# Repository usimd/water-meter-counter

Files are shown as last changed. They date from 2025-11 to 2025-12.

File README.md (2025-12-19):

# Inductive water meter counter with S0 interface for GSB-8 meters

This is a custom water meter counter project to get an interface to analog water meter readings
for subsequent usage in Homeassistant. The project is outputting its readings via a generic S0
interface, though, to enable other use cases as well.

It features a custom 3D-printable model to snap on to the GSB-8 meter that houses the PCB. The
software doing the actual work is located in the [`firmware`](./firmware) folder. Since it is
based on a Microchip PIC controller, it requires the respective infrastructure to build.

Bundled assets are available as GitHub releases, including compiled firmware, 3MF file of the
housing and Gerber files for PCB production.

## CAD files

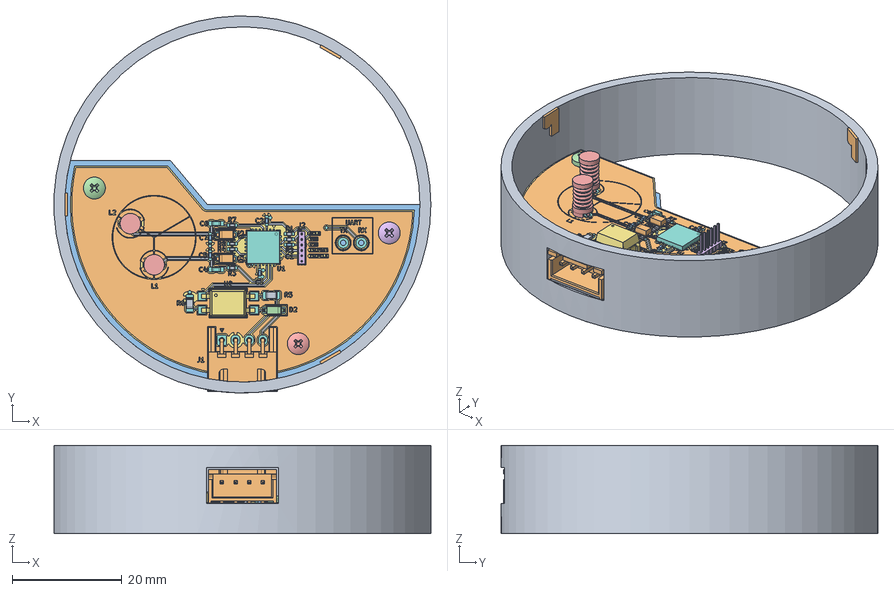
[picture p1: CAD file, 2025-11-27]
Watermeter_Cover.FCStd
68.8 x 68.8 x 16.1 mm
Cover_Base
Pins
PCB_Mount
M2x5-Schraube
M2x5-Schraube003
M2x5-Schraube004
Pcb_d2e1
topPads_d2e1
topTracks_d2e1
topZones_d2e1
botPads_d2e1
botTracks_d2e1
botZones_d2e1
botSilks_9d78
topSilks_90ac
C4_C_0603_1608Metric_6c412fb28b8f x 2
R8_R_0402_1005Metric_e01b41909d19 x 6
D1_D_SOD_123F_9a9cfb070a70 x 2
C7_C_0402_1005Metric_09611c456d0c x 5
D2_D_SOD-123_464a0c5e4694
L1_Fusion_5f2570e535e7 x 2
J2_PinHeader_1x06_P100mm_Vertical_8e52eaff288e
U2_SSO_4_67x51mm_P254mm_Clearance8mm_ef5c1f87034f
U1_QFN-28-1EP_6x6mm_Pitch0.65mm_9500fd6ea776
R5_R_0805_2012Metric_8a1f76670d96 x 2
J1_JST_S4B_XH_A_36b230cda832

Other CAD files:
Watermeter_Cover.3mf
water-meter-counter-B_Silkscreen.dxf
water-meter-counter-F_Silkscreen.dxf

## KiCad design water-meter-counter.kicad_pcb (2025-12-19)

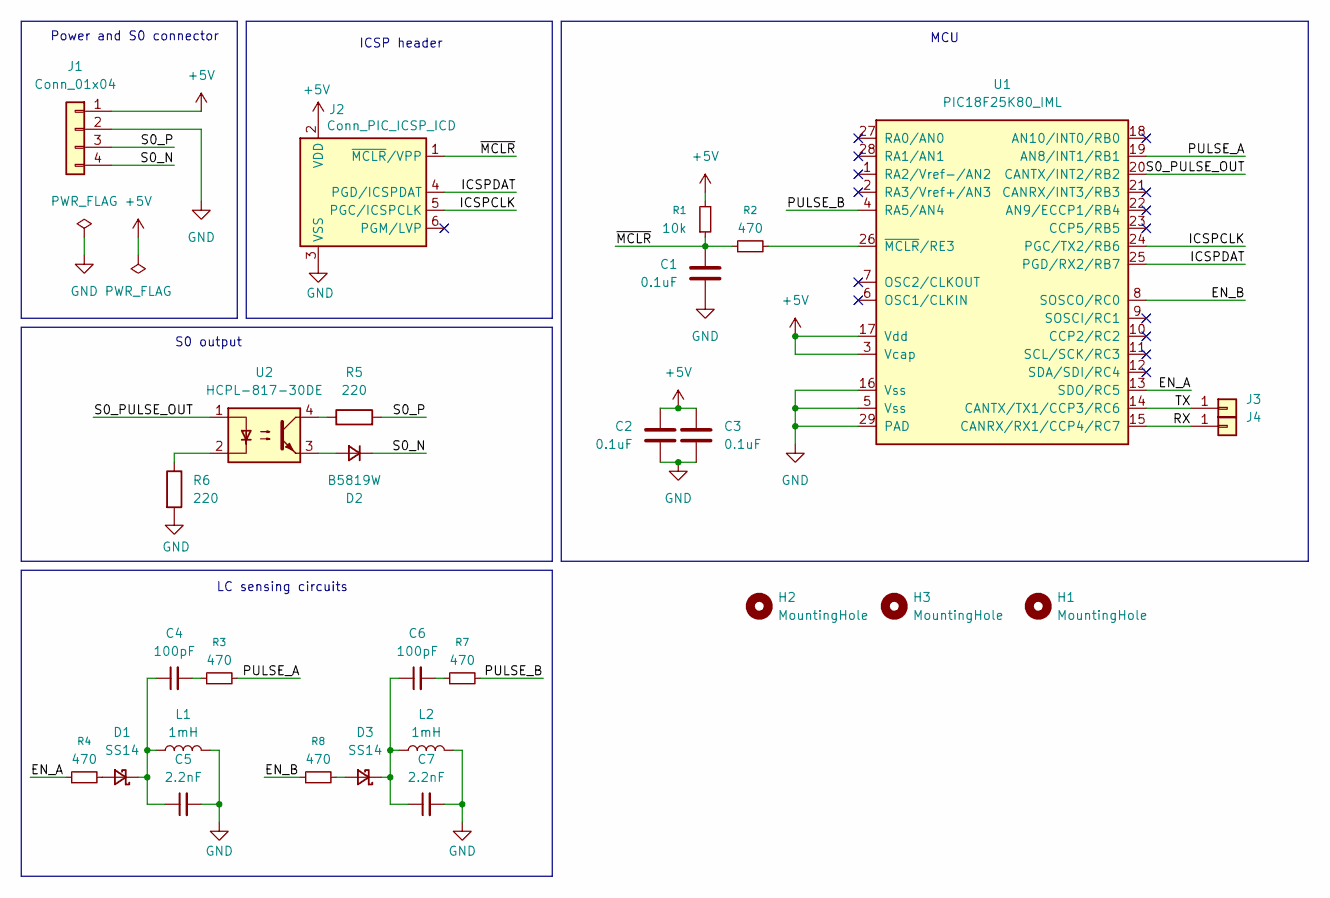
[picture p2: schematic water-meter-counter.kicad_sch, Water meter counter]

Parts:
C1, C2, C3: 0.1uF; C_0402_1005Metric_Pad0.74x0.62mm_HandSolder
C4, C6: 100pF; C_0603_1608Metric_Pad1.08x0.95mm_HandSolder
C5, C7: 2.2nF; C_0402_1005Metric_Pad0.74x0.62mm_HandSolder
D1, D3: SS14; D_SOD-123F
D2: B5819W; D_SOD-123
H1, H2, H3: MountingHole; MountingHole_2.2mm_M2_ISO7380
J1: Conn_01x04; JST_XH_S4B-XH-A_1x04_P2.50mm_Horizontal
J2: Conn_PIC_ICSP_ICD; PinHeader_1x06_P1.00mm_Vertical
J3, J4: Conn_01x01; TestPoint_Keystone_5000-5004_Miniature
L1, L2: 1mH; L_Radial_D4.80mm_P2.50mm_Fastron_05HCP; MPN 05HCP-102K-51
R1: 10k; R_0402_1005Metric_Pad0.72x0.64mm_HandSolder
R2, R3, R4, R7, R8: 470; R_0402_1005Metric_Pad0.72x0.64mm_HandSolder
R5, R6: 220; R_0805_2012Metric_Pad1.20x1.40mm_HandSolder
U1: PIC18F25K80_IML; QFN-28-1EP_6x6mm_P0.65mm_EP4.25x4.25mm
U2: HCPL-817-30DE; SSO-4_6.7x5.1mm_P2.54mm_Clearance8mm

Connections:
+5V: C2.1, C3.1, J1.1, J2.2 (VDD), R1.2, U1.3 (Vcap), U1.17 (Vdd)
/EN_A: R4.1, U1.13 (SDO/RC5)
/EN_B: R8.1, U1.8 (SOSCO/RC0)
/ICSPCLK: J2.5 (PGC/ICSPCLK), U1.24 (PGC/TX2/RB6)
/ICSPDAT: J2.4 (PGD/ICSPDAT), U1.25 (PGD/RX2/RB7)
/PULSE_A: R3.2, U1.19 (AN8/INT1/RB1)
/PULSE_B: R7.2, U1.4 (RA5/AN4)
/RX: J4.1, U1.15 (CANRX/RX1/CCP4/RC7)
/S0_N: D2.1 (K), J1.4
/S0_P: J1.3, R5.2
/S0_PULSE_OUT: U1.20 (CANTX/INT2/RB2), U2.1
/TX: J3.1, U1.14 (CANTX/TX1/CCP3/RC6)
/~MCLR: C1.1, J2.1 (~MCLR/VPP), R1.1, R2.1
GND: C1.2, C2.2, C3.2, C5.2, C7.2, J1.2, J2.3 (VSS), L1.2, L2.2, R6.2, U1.5 (Vss), U1.16 (Vss), U1.29 (PAD)
unnamed: C4.2, R3.1
unnamed: C6.2, R7.1
unnamed: D1.2 (A), R4.2
unnamed: C4.1, C5.1, D1.1 (K), L1.1
unnamed: D2.2 (A), U2.3
unnamed: D3.2 (A), R8.2
unnamed: C6.1, C7.1, D3.1 (K), L2.1
unnamed: R5.1, U2.4
unnamed: R6.1, U2.2
unnamed: R2.2, U1.26 (~MCLR/RE3)

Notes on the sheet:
LC sensing circuits
MCU
ICSP header
Power and S0 connector
S0 output

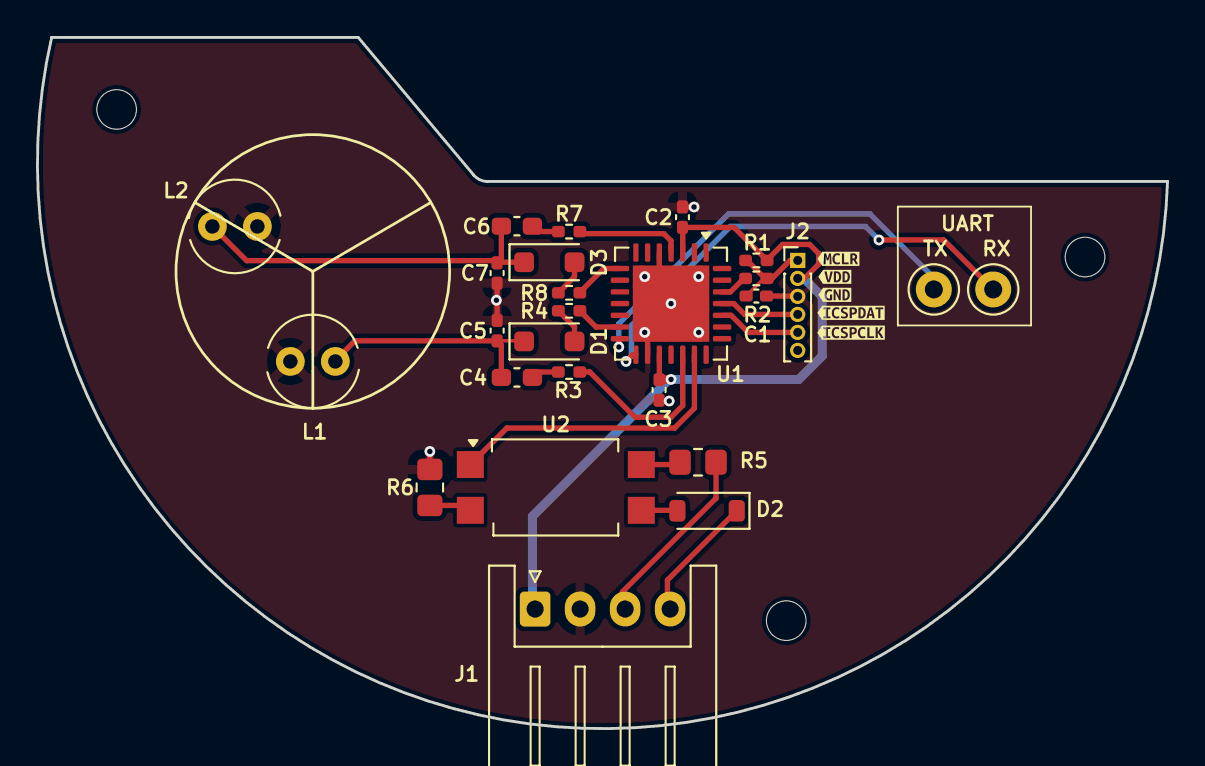
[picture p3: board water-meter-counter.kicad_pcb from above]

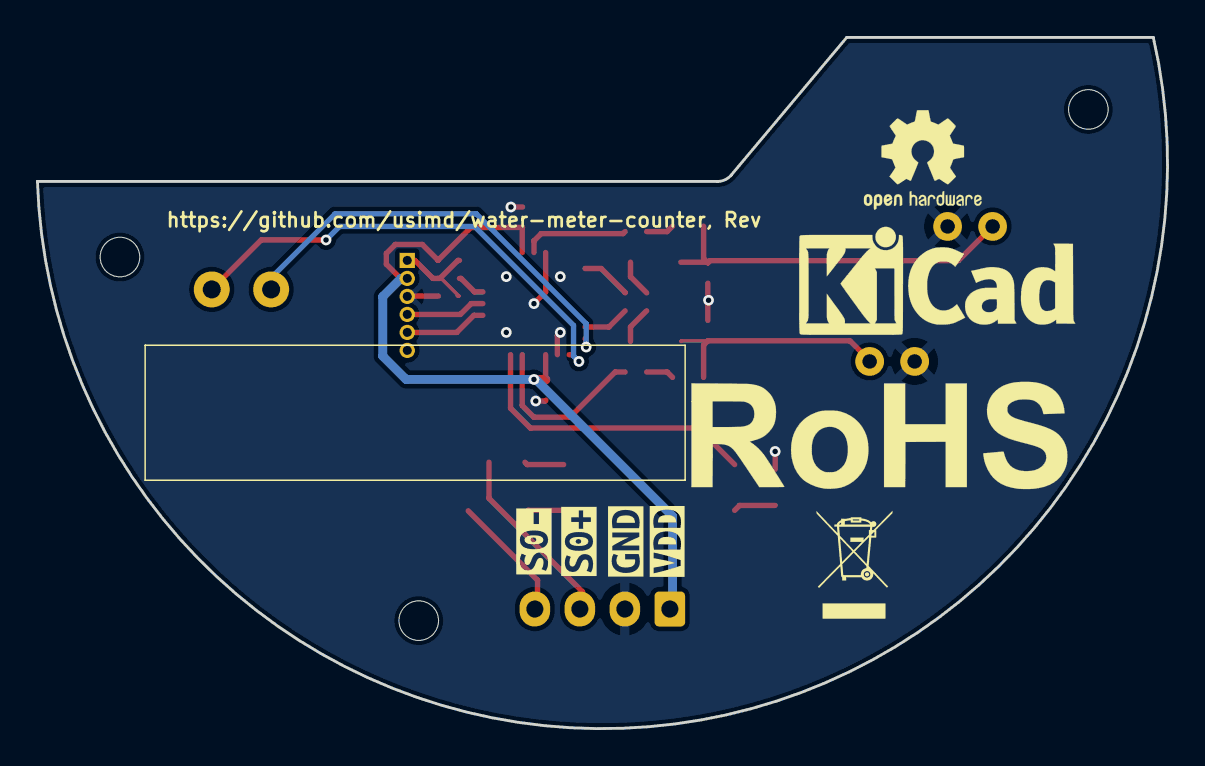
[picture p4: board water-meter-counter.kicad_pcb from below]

Board: 2 copper layers, 62.8 x 38.4 mm, 38 parts (4 on the bottom side), 24 nets.

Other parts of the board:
kibuzzard-6924F1AD: G***; kibuzzard-6924F1AD
kibuzzard-6924F10E: G***; kibuzzard-6924F10E
kibuzzard-6924F13D: G***; kibuzzard-6924F13D
kibuzzard-6924F19F: G***; kibuzzard-6924F19F
kibuzzard-6924F128: G***; kibuzzard-6924F128
kibuzzard-6924F218: G***; kibuzzard-6924F218
kibuzzard-6924F221: G***; kibuzzard-6924F221
kibuzzard-6945164F: G***; kibuzzard-6945164F
kibuzzard-69451647: G***; kibuzzard-69451647

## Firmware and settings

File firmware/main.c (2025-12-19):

 /*
 * MAIN Generated Driver File
 * 
 * @file main.c
 * 
 * @defgroup main MAIN
 * 
 * @brief This is the generated driver implementation file for the MAIN driver.
 *
 * @version MAIN Driver Version 1.0.2
 *
 * @version Package Version: 3.1.2
*/

/*
? [2025] Microc� [2025] Microchip Technology Inc. and its subsidiaries.

    Subject to your compliance with these terms, you may use Microchip 
    software and any derivatives exclusively with Microchip products. 
    You are responsible for complying with 3rd party license terms  
    applicable to your use of 3rd party software (including open source  
    software) that may accompany Microchip software. SOFTWARE IS ?AS IS.? 
    NO WARRANTIES, WHETHER EXPRESS, IMPLIED OR STATUTORY, APPLY TO THIS 
    SOFTWARE, INCLUDING ANY IMPLIED WARRANTIES OF NON-INFRINGEMENT,  
    MERCHANTABILITY, OR FITNESS FOR A PARTICULAR PURPOSE. IN NO EVENT 
    WILL MICROCHIP BE LIABLE FOR ANY INDIRECT, SPECIAL, PUNITIVE, 
    INCIDENTAL OR CONSEQUENTIAL LOSS, DAMAGE, COST OR EXPENSE OF ANY 
    KIND WHATSOEVER RELATED TO THE SOFTWARE, HOWEVER CAUSED, EVEN IF 
    MICROCHIP HAS BEEN ADVISED OF THE POSSIBILITY OR THE DAMAGES ARE 
    FORESEEABLE. TO THE FULLEST EXTENT ALLOWED BY LAW, MICROCHIP?S 
    TOTAL LIABILITY ON ALL CLAIMS RELATED TO THE SOFTWARE WILL NOT 
    EXCEED AMOUNT OF FEES, IF ANY, YOU PAID DIRECTLY TO MICROCHIP FOR 
    THIS SOFTWARE.
*/
#include "mcc_generated_files/system/system.h"
#include "water_meter.h"
#include <xc.h>

/*
    Main application
    
    Water Meter Counter using dual LC tank circuits (CMP1, CMP2)
    with S0 pulse output interface and deep sleep mode.
    
    Pin Assignment:
    - RC5: LC Tank A input (CMP1 comparator)
    - RC0: LC Tank B input (CMP2 comparator)
    - RB2: S0 output (pulse interface, ~100ms pulses)
    
    Power Management:
    - Enters deep sleep mode to minimize power consumption
    - Wakes up every 1.5-2 seconds to check for water meter rotations
    - Q_3 = 2.5 m³/h: Minimum rotation time = 1.44 seconds
    - Safe timeout: 1500ms minimum to ensure no rotations are missed
*/

int main(void)
{
    SYSTEM_Initialize();
    INTERRUPT_GlobalInterruptHighEnable(); 
    INTERRUPT_GlobalInterruptLowEnable(); 
    INTERRUPT_PeripheralInterruptEnable(); 

    // CRITICAL: Force RC5 and RC0 to be DIGITAL OUTPUTS
    // MCC configures them as inputs and regenerates on build
    // Must be IMMEDIATELY after SYSTEM_Initialize() before anything else uses these pins
    TRISCbits.TRISC5 = 0;  // RC5 (LCA) = output
    TRISCbits.TRISC0 = 0;  // RC0 (LCB) = output
    
    // CRITICAL: Ensure RA5 and RB1 (comparator inputs) are in ANALOG mode
    // Comparators REQUIRE analog inputs to work properly!
    // Digital mode uses Schmitt trigger which clips small AC signals
    // ANSELA is at 0xF1C (bit 4 for RA5), ANSELB is at 0xF1D (bit 1 for RB1)
    *(volatile unsigned char*)0xF1C |= 0x10;   // Set bit 4 (RA5) - set to ANALOG mode
    *(volatile unsigned char*)0xF1D |= 0x02;   // Set bit 1 (RB1) - set to ANALOG mode 

    // Initialize water meter counter module
    WaterMeter_Initialize();
    
    // CRITICAL: Force RC5 and RC0 BACK to outputs after WaterMeter_Initialize()
    // WaterMeter_Initialize() calls CMP1/2_Initialize() which may reset pin modes
    TRISCbits.TRISC5 = 0;  // RC5 (LCA) = output
    TRISCbits.TRISC0 = 0;  // RC0 (LCB) = output
    
    // CRITICAL FIX: MCC has a bug where register values aren't set properly
    // Must be AFTER WaterMeter_Initialize() because it calls CMP1/2_Initialize()
    // which would overwrite our register settings
    // CVref: 0xBA = CVREN=1, CVROE=1, CVRSS=0, CVR=10 (generates ~1.72V on RA2)
    // Formula: Vref = (CVR+1)*5/32 = (10+1)*5/32 = 1.72V
    // CVROE=1 enables the output on RA2 so comparators can use it as threshold
    CVRCON = 0xBA;
    
    // Comparators: 0x9C = CNCH=1(C1INB), CPCH=1(CVREF), EVPOL=0, CPOL=0, COE=1, CON=1
    CM1CON = 0x9C;  // Compare C1INB input against CVref
    CM2CON = 0x98;  // Changed from 0x9C - COE=0 to free RC0 for GPIO (was blocking LCB drive)
    
    // Enable sleep mode with safe timeout for Q_3 = 2.5 m³/h
    // 1 liter per 1.44 seconds minimum, use 1500ms safe timeout
    WaterMeter_SetSleepEnabled(true);
    
    // Wait for UART to settle
    __delay_ms(100);
    printf("\r\n=== Water Meter Counter Started ===\r\n");
    printf("Q_3: 2.5 m³/h | S0 Output: RB2\r\n");
    printf("\r\nRunning hardware diagnostic test...\r\n");
    
    // Run diagnostic test to verify LC tank hardware is working
    WaterMeter_DiagnosticTest();

    while(1)
    {
        // Process water meter counter state machine
        // This monitors the LC tank circuits and generates S0 pulses
        if (WaterMeter_Process()) {
            // A full rotation was detected
            // S0 pulse is automatically generated by the module
            printf("\r\nRotation detected. Count: %lu\r\n", WaterMeter_GetRotationCount());
            // Wait for UART transmission to complete before sleeping
            while (!EUSART1_IsTxDone()) {
                __delay_us(10);
            }
        }
        
        // Debug output for LC tank oscillation measurements
        printf("LCA: %3d (metal:%d, thr:%d)  LCB: %3d (metal:%d, thr:%d)  |  CMP1=%d CMP2=%d\r\n", 
               WaterMeter_GetLCA_OscillationCount(),
               WaterMeter_GetLCA_State(),
               18,  /* Calibrated threshold */
               WaterMeter_GetLCB_OscillationCount(),
               WaterMeter_GetLCB_State(),
               18,  /* Calibrated threshold */
               WaterMeter_GetCMP1_Output(),
               WaterMeter_GetCMP2_Output());
        // Wait for UART transmission to complete before sleeping
        while (!EUSART1_IsTxDone()) {
            __delay_us(10);
        }
        
        // Add delay between measurements to prevent continuous polling
        // This gives time for LC tank to fully stabilize and reduces power consumption
        __delay_ms(500);  // 500ms delay between measurements
        
        // Enter deep sleep mode if system is idle
        // Device will wake up every 3 seconds to check for rotations
        // Timeout accounts for: disc geometry (7.5mm radius, 120° offset inductors, half metal)
        if (WaterMeter_CanSleep()) {
            WaterMeter_EnterDeepSleep(3000);  /* 3 second timeout for safety with geometry */
        }
    }    
}

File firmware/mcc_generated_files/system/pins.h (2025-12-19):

/**
 * Generated Pins header File
 * 
 * @file pins.h
 * 
 * @defgroup  pinsdriver Pins Driver
 * 
 * @brief This is generated driver header for pins. 
 *        This header file provides APIs for all pins selected in the GUI.
 *
 * @version Driver Version  3.1.1
*/

/*
� [2025] Microchip Technology Inc. and its subsidiaries.

    Subject to your compliance with these terms, you may use Microchip 
    software and any derivatives exclusively with Microchip products. 
    You are responsible for complying with 3rd party license terms  
    applicable to your use of 3rd party software (including open source  
    software) that may accompany Microchip software. SOFTWARE IS ?AS IS.? 
    NO WARRANTIES, WHETHER EXPRESS, IMPLIED OR STATUTORY, APPLY TO THIS 
    SOFTWARE, INCLUDING ANY IMPLIED WARRANTIES OF NON-INFRINGEMENT,  
    MERCHANTABILITY, OR FITNESS FOR A PARTICULAR PURPOSE. IN NO EVENT 
    WILL MICROCHIP BE LIABLE FOR ANY INDIRECT, SPECIAL, PUNITIVE, 
    INCIDENTAL OR CONSEQUENTIAL LOSS, DAMAGE, COST OR EXPENSE OF ANY 
    KIND WHATSOEVER RELATED TO THE SOFTWARE, HOWEVER CAUSED, EVEN IF 
    MICROCHIP HAS BEEN ADVISED OF THE POSSIBILITY OR THE DAMAGES ARE 
    FORESEEABLE. TO THE FULLEST EXTENT ALLOWED BY LAW, MICROCHIP?S 
    TOTAL LIABILITY ON ALL CLAIMS RELATED TO THE SOFTWARE WILL NOT 
    EXCEED AMOUNT OF FEES, IF ANY, YOU PAID DIRECTLY TO MICROCHIP FOR 
    THIS SOFTWARE.
*/

#ifndef PINS_H
#define PINS_H

#include <xc.h>

#define INPUT   1
#define OUTPUT  0

#define HIGH    1
#define LOW     0

#define ANALOG      1
#define DIGITAL     0

#define PULL_UP_ENABLED      1
#define PULL_UP_DISABLED     0

// get/set RA5 aliases
#define IO_RA5_TRIS                 TRISAbits.TRISA5
#define IO_RA5_LAT                  LATAbits.LATA5
#define IO_RA5_PORT                 PORTAbits.RA5
#define IO_RA5_WPU                  WPUAbits.
#define IO_RA5_OD                   ODCONAbits.
#define IO_RA5_ANS                  ANSELAbits.ANSEL4
#define IO_RA5_SetHigh()            do { LATAbits.LATA5 = 1; } while(0)
#define IO_RA5_SetLow()             do { LATAbits.LATA5 = 0; } while(0)
#define IO_RA5_Toggle()             do { LATAbits.LATA5 = ~LATAbits.LATA5; } while(0)
#define IO_RA5_GetValue()           PORTAbits.RA5
#define IO_RA5_SetDigitalInput()    do { TRISAbits.TRISA5 = 1; } while(0)
#define IO_RA5_SetDigitalOutput()   do { TRISAbits.TRISA5 = 0; } while(0)
#define IO_RA5_SetPullup()          do { WPUAbits. = 1; } while(0)
#define IO_RA5_ResetPullup()        do { WPUAbits. = 0; } while(0)
#define IO_RA5_SetPushPull()        do { ODCONAbits. = 0; } while(0)
#define IO_RA5_SetOpenDrain()       do { ODCONAbits. = 1; } while(0)
#define IO_RA5_SetAnalogMode()      do { ANSELAbits.ANSEL4 = 1; } while(0)
#define IO_RA5_SetDigitalMode()     do { ANSELAbits.ANSEL4 = 0; } while(0)

// get/set RB1 aliases
#define IO_RB1_TRIS                 TRISBbits.TRISB1
#define IO_RB1_LAT                  LATBbits.LATB1
#define IO_RB1_PORT                 PORTBbits.RB1
#define IO_RB1_WPU                  WPUBbits.WPUB1
#define IO_RB1_OD                   ODCONBbits.
#define IO_RB1_ANS                  ANSELBbits.ANSEL8
#define IO_RB1_SetHigh()            do { LATBbits.LATB1 = 1; } while(0)
#define IO_RB1_SetLow()             do { LATBbits.LATB1 = 0; } while(0)
#define IO_RB1_Toggle()             do { LATBbits.LATB1 = ~LATBbits.LATB1; } while(0)
#define IO_RB1_GetValue()           PORTBbits.RB1
#define IO_RB1_SetDigitalInput()    do { TRISBbits.TRISB1 = 1; } while(0)
#define IO_RB1_SetDigitalOutput()   do { TRISBbits.TRISB1 = 0; } while(0)
#define IO_RB1_SetPullup()          do { WPUBbits.WPUB1 = 1; } while(0)
#define IO_RB1_ResetPullup()        do { WPUBbits.WPUB1 = 0; } while(0)
#define IO_RB1_SetPushPull()        do { ODCONBbits. = 0; } while(0)
#define IO_RB1_SetOpenDrain()       do { ODCONBbits. = 1; } while(0)
#define IO_RB1_SetAnalogMode()      do { ANSELBbits.ANSEL8 = 1; } while(0)
#define IO_RB1_SetDigitalMode()     do { ANSELBbits.ANSEL8 = 0; } while(0)

// get/set RB2 aliases
#define S0_TRIS                 TRISBbits.TRISB2
#define S0_LAT                  LATBbits.LATB2
#define S0_PORT                 PORTBbits.RB2
#define S0_WPU                  WPUBbits.WPUB2
#define S0_OD                   ODCONBbits.
#define S0_ANS                  ANSELBbits.
#define S0_SetHigh()            do { LATBbits.LATB2 = 1; } while(0)
#define S0_SetLow()             do { LATBbits.LATB2 = 0; } while(0)
#define S0_Toggle()             do { LATBbits.LATB2 = ~LATBbits.LATB2; } while(0)
#define S0_GetValue()           PORTBbits.RB2
#define S0_SetDigitalInput()    do { TRISBbits.TRISB2 = 1; } while(0)
#define S0_SetDigitalOutput()   do { TRISBbits.TRISB2 = 0; } while(0)
#define S0_SetPullup()          do { WPUBbits.WPUB2 = 1; } while(0)
#define S0_ResetPullup()        do { WPUBbits.WPUB2 = 0; } while(0)
#define S0_SetPushPull()        do { ODCONBbits. = 0; } while(0)
#define S0_SetOpenDrain()       do { ODCONBbits. = 1; } while(0)
#define S0_SetAnalogMode()      do { ANSELBbits. = 1; } while(0)
#define S0_SetDigitalMode()     do { ANSELBbits. = 0; } while(0)

// get/set RC0 aliases
#define LCB_TRIS                 TRISCbits.TRISC0
#define LCB_LAT                  LATCbits.LATC0
#define LCB_PORT                 PORTCbits.RC0
#define LCB_WPU                  WPUCbits.WPUC0
#define LCB_OD                   ODCONCbits.ODCC0
#define LCB_ANS                  ANSELCbits.
#define LCB_SetHigh()            do { LATCbits.LATC0 = 1; } while(0)
#define LCB_SetLow()             do { LATCbits.LATC0 = 0; } while(0)
#define LCB_Toggle()             do { LATCbits.LATC0 = ~LATCbits.LATC0; } while(0)
#define LCB_GetValue()           PORTCbits.RC0
#define LCB_SetDigitalInput()    do { TRISCbits.TRISC0 = 1; } while(0)
#define LCB_SetDigitalOutput()   do { TRISCbits.TRISC0 = 0; } while(0)
#define LCB_SetPullup()          do { WPUCbits.WPUC0 = 1; } while(0)
#define LCB_ResetPullup()        do { WPUCbits.WPUC0 = 0; } while(0)
#define LCB_SetPushPull()        do { ODCONCbits.ODCC0 = 0; } while(0)
#define LCB_SetOpenDrain()       do { ODCONCbits.ODCC0 = 1; } while(0)
#define LCB_SetAnalogMode()      do { *(volatile unsigned char*)0xF1E |= 0x08; } while(0)
#define LCB_SetDigitalMode()     do { *(volatile unsigned char*)0xF1E &= ~0x08; } while(0)
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

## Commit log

2025-12-19 First draft of firmware
    [water-meter-counter-B_Silkscreen.dxf, water-meter-counter-F_Silkscreen.dxf, water-meter-counter.kicad_pcb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]
2026-01-21 Fix RC0 GPIO, improve S0 resolution to 0.5L/pulse, fix MCC pin macros
    - config_bits.c: Set SOSCSEL=DIG to release RC0/RC1 from SOSC mode
    - config_bits.c: Add comment that XINST=OFF is required for XC8
    - main.c: Add runtime SOSCGO=0, T1OSCEN=0, SOSCEN=0 to fully disable SOSC
    - main.c: Update comments for 0.5L/pulse resolution and correct pin assignments
    - water_meter.c: Re-enable dual LC tank sensing (LCB was disabled for debugging)
    - water_meter.c: Generate S0 pulse on each LC state transition (was every 2)
    - pins.h: Fix broken MCC macros for RC0, RC5, RC6, RC7, RB2 - these pins
    have no WPU, ODCON, or ANSEL bits; macros are now safe no-ops
    The half-metal disc with 120deg inductor offset p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
2026-10-27 Rev2 firmware, release CI and licensing
    Firmware:
    - Comparator-only ring-down sensing on both LC tanks (Timer1 gated by
    comparator 1 against CVREF), no ADC.
    - New hardware-independent rotation decoder (B pass detection, direction
    from A's first vs. last third of the pass).
    - Sleep between samples with WDT wake-up, S0 pulse timed by TMR0.
    - DEBUG_STREAM selectable by the build; user.cmake builds a second
    default-debug image next to the production one.
    - Commit the MPLAB-generated CMake files so CI can build; pack path
    defaults to $HOME/.mchp_packs.
    CI:
    - Fix firmware build (preset, XC8 from setup-xc-action).
    - Hardware job on KiCad 10: ERC/DRC reports, schematic PDF, BOM,
    pick-and-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
2026-10-28 Half-litre S0 resolution and slow-flow baseline fix
    Count each revolution in two half steps (B pass and rest phase), so
    one S0 pulse is 0.5 L (2000 pulses/m3). Reverse half steps are netted
    against forward ones before pulses resume. The B rest baseline now
    rises only one tick per 16 samples, so slow ramps at a trickle no
    longer drag it into the pass level and miss litres.
    Verified against the Python model on recorded and fuzzed logs and on
    the bench down to ~2 L/min. README gains an ESPHome example.
